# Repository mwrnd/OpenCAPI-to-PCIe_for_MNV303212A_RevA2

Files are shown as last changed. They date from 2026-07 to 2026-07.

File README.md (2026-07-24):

**Work-In-Progress**: Notes need updating. v1.1 Gerbers need to be manufactured and tested.

# PCIe to Innova-2 MNV303212A RevA2 SlimSAS8x

This is a variant of the [OpenCAPI-to-PCIe](https://github.com/mwrnd/OpenCAPI-to-PCIe) project optimized for the **Innova-2 MNV303212A Rev:A2**.

The [Open Coherant Accelerator Processor Interface (OpenCAPI)](https://opencapi.org/wp-content/uploads/2022/07/OpenCAPI-Overview.pdf) [was a standard](https://opencapi.org/2022/08/09/cxl-consortium-and-opencapi-consortium-sign-letter-of-intent-to-transfer-opencapi-specifications-to-cxl/) that had FPGA-based [Advanced Accelerated Cable (AAC)](https://files.openpower.foundation/s/xSQPe6ypoakKQdq/download/25Gbps-spec-20171108.pdf) [Add-In cards](https://opencapi.org/wp-content/uploads/2018/12/OpenCAPI-Tech-SC18-Exhibitor-Forum.pdf) such as [ADM-PCIE-9H3](https://www.alpha-data.com/product/adm-pcie-9h3/), [ADM-PCIE-9H7](https://www.alpha-data.com/alpha-data-release-adm-pcie-9h7-data-center-board-with-xilinx-virtex-ultrascale-hbm-fpga/), [ADM-PCIE-9V3](https://www.alpha-data.com/product/adm-pcie-9v3/), [ADM-PCIE-9V5](https://www.alpha-data.com/product/adm-pcie-9v5/), [BittWare XUP-VV4](https://www.bittware.com/fpga/xup-vv4/), [BittWare XUP-VVH](https://www.bittware.com/fpga/xup-vvh/), and [Nvidia Innova-2 Flex SmartNIC](https://www.nvidia.com/en-us/networking/ethernet/innova-2-flex/).

The OpenCAPI interface is based on [PCI-Express](https://en.wikipedia.org/wiki/PCI_Express) and uses a [SlimSAS 8X](https://en.wikipedia.org/wiki/Serial_Attached_SCSI) (SFF-8654) Connector. This adapter enables connecting an OpenCAPI FPGA board to a host using PCIe over a SlimSAS cable.

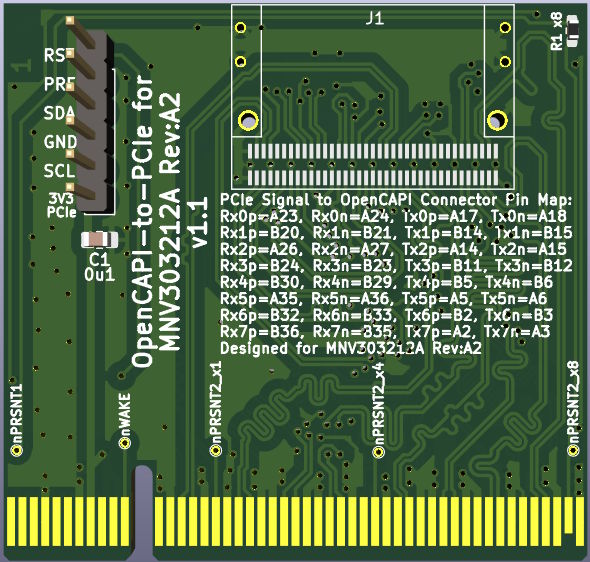
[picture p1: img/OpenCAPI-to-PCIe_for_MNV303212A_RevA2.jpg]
OpenCAPI-to-PCIe Board


## PCB Layout

4-Layer PCB. Inner 2 layers are GND planes. Differential pair are matched to a length of 61mm +/- 1mm both inter-pair and intra-pair (N-to-P).

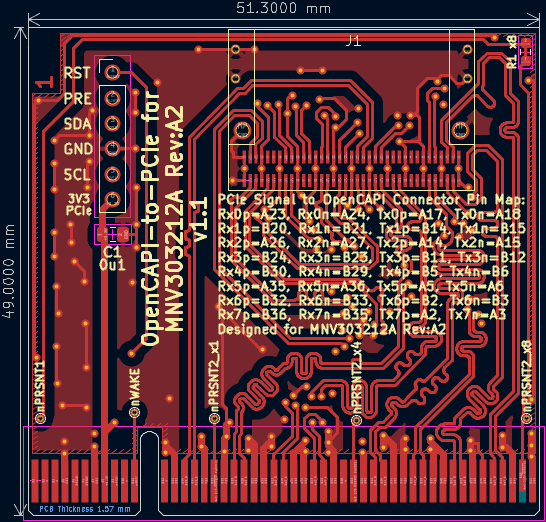
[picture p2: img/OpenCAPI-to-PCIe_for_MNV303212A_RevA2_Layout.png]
OpenCAPI to PCIe x8 PCB Layout


## Schematic

Note the reverse channel ordering and swapped `_P` and `_N` for RX3, 4, and 7. This is done to optimize for the `MNV303212A-ADLT Rev:A2` board. Technically it should not matter. PCIe features automatic `_P-to-_N` swapping and the FPGA supports arbitrary lane assignment. I did this to eliminate all possible conflating problems while tracking down reliability issues.

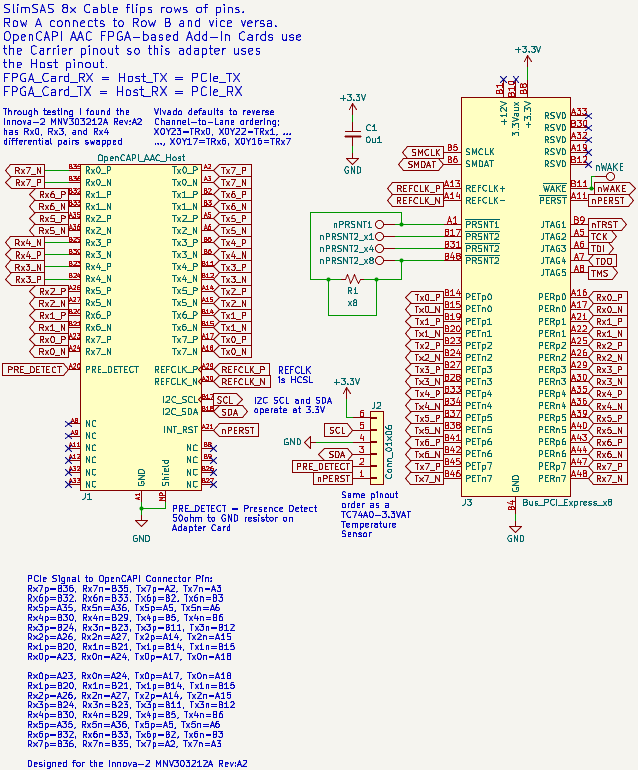
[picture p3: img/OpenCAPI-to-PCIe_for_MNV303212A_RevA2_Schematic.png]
OpenCAPI to PCIe x8 Schematic


## Design Notes

Only a single component is needed for the adapter, a [U10A474200T](https://www.digikey.com/en/products/detail/amphenol-cs-commercial-products/U10A474200T/14632855)/[U10A474240T](https://www.digikey.com/en/products/detail/amphenol-cs-commercial-products/U10A474240T/17066204) SlimSAS 8x Right-Angle SMD Connector.

A SlimSAS 8x Cable such as the [3M 8ES8-1DF21](https://www.trustedparts.com/en/search/8ES8-1DF21)([Datasheet](https://multimedia.3m.com/mws/media/1398233O/3m-slimline-twin-ax-assembly-sff-8654-x8-30awg-78-5100-2665-8.pdf)) is required to use the adapter with an OpenCAPI FPGA Board.

Resistor **R1** is shorted to connect `nPRSNT1` to `nPRSNT2_x8`. The trace can be scratched off and `nPRSNT1` can be connected to `nPRSNT2_x1` or `nPRSNT2_x4` to limit the PCIe lane width.

### PCB Stackup

I am using values from [JLCPCB](https://jlcpcb.com/capabilities/pcb-capabilities).

4-Layer Stackup

### Trace Impedance Control

OpenCAPI uses 85ohm impedance cables. I played with the values until I got the loosest differential pair coupling that is manufacturable with larger tolerances.

85ohm Differential Impedance in DigiKey Calculator

## Testing

The [innova2_xdma_opencapi](https://github.com/mwrnd/innova2_xdma_opencapi) project is designed to test this `OpenCAPI-to-PCIe for MNV303212A RevA2` Adapter using an [Innova2 Flex SmartNIC Rev:A2 board](https://github.com/mwrnd/innova2_flex_xcku15p_notes).

The Innova2 SmartNIC's XCKU15P FPGA does not have its Configuration Block in the same column as the OpenCAPI GTY transceivers so it is impossible to configure the FPGA within the [PCIe Specification's 100ms time limit](https://pcisig.com/specifications/ecr_ecn_process?speclib=100+ms).

Innova2 XCKU15P Bank Diagram

Motherboard boot must therefore be delayed to allow the FPGA to configure itself before the OpenCAPI-to-PCIe device is enumerated by the host system. This can be accomplished by toggling the POWER button, then pressing and holding the RESET button for a second before releasing it. Or, [connect a capacitor across the reset pins of an ATX motherboard's Front Panel Header](https://github.com/mwrnd/ATX_Boot_Delay):

Delay Boot Using Capacitor across Front Panel Header Reset Pins

### Cable Performance

Using a [3M 8ES8-1DF21-0.75](https://www.trustedparts.com/en/search/8ES8-1DF21-0.75) cable:

System with 3M 8ES8-1DF21-0.75 Cable

PCIe Link Status is usually excellent:

lspci Link Status

Using an [SFPCables.com SFF-8654 to SFF-8654 8i](https://www.sfpcables.com/24g-internal-slimsas-sff-8654-to-sff-8654-8i-cable-straight-to-90-degree-left-angle-8x-12-sas-4-0-85-ohm-0-5-1-meter) cable:

System with SFPCables SFF-8654 8i 85Ohm Cable

PCIe Link Status is downgraded:

lspci Link Status

### Additional OpenCAPI Signals

Additional useful signals from the OpenCAPI connector are routed to a 6x1 0.1" Header ([DigiKey](https://www.digikey.com/en/products/detail/sullins-connector-solutions/PPTC061LFBN-RC/810145)). The pinout matches a [TC74 I2C Temperature Sensor](https://www.microchip.com/en-us/product/tc74) ([DigiKey](https://www.digikey.com/en/products/detail/microchip-technology/TC74A0-3-3VAT/442720)) for testing I2C. I2C pull-ups are on the AAC Add-in card (Innova-2). Note 3.3V is from the PCIe connector. **PRE** is a Presence Detect pin which is connected to GND via a 50-Ohm resistor on the OpenCAPI AAC Add-In card (Innova-2). **RST** is connected to PCIe/OpenCAPI RESET.

TC74A0-3.3VAT in OpenCAPI-to-PCIe Adapter

The [innova2_xdma_opencapi](https://github.com/mwrnd/innova2_xdma_opencapi) project features the ability to [test](https://github.com/mwrnd/innova2_xdma_opencapi/blob/main/README.md#opencapi-i2c-over-xdma) a TC74Ax-3.3VAT in an OpenCAPI-to-PCIe Adapter.

TC74A0-3.3VAT Testing in a System

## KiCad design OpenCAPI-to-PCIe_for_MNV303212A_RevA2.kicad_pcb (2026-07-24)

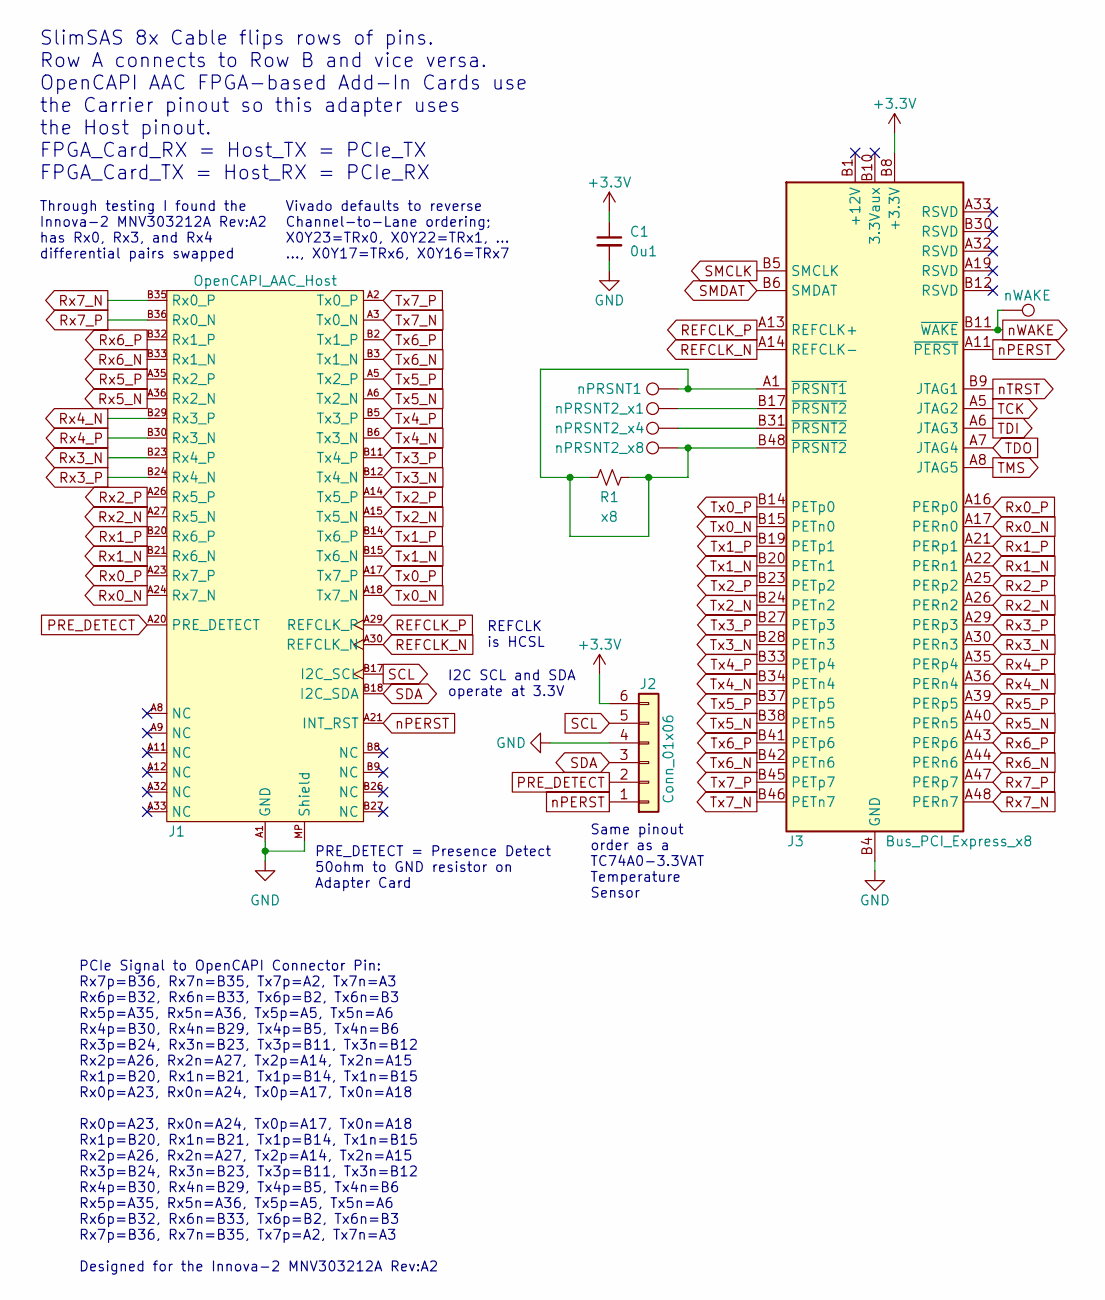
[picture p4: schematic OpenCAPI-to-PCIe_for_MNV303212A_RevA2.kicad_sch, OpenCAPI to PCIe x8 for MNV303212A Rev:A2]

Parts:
C1: 0u1; C_0805_2012Metric_Pad1.18x1.45mm_HandSolder
J1: OpenCAPI_AAC_Host; SlimSAS_8x_RA_U10-A474
J2: Conn_01x06; PinHeader_1x06_P2.54mm_Vertical
J3: Bus_PCI_Express_x8; BUS_PCIexpress_x8
R1: x8; R_0603_1608Metric_Pad0.98x0.95mm_HandSolder
TP1: nPRSNT1; TestPoint_THTPad_D1.0mm_Drill0.5mm
TP2: nPRSNT2_x1; TestPoint_THTPad_D1.0mm_Drill0.5mm
TP3: nPRSNT2_x4; TestPoint_THTPad_D1.0mm_Drill0.5mm
TP4: nWAKE; TestPoint_THTPad_D1.0mm_Drill0.5mm
TP5: nPRSNT2_x8; TestPoint_THTPad_D1.0mm_Drill0.5mm

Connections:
+3.3V: C1.1, J2.6, J3.A9 (+3.3V), J3.A10 (+3.3V), J3.B8 (+3.3V)
GND: C1.2, J1.A1 (GND), J1.A4 (GND), J1.A7 (GND), J1.A10 (GND), J1.A13 (GND), J1.A16 (GND), J1.A19 (GND), J1.A22 (GND), J1.A25 (GND), J1.A28 (GND), J1.A31 (GND), J1.A34 (GND), J1.A37 (GND), J1.B1 (GND), J1.B4 (GND), J1.B7 (GND), J1.B10 (GND), J1.B13 (GND), J1.B16 (GND), J1.B19 (GND), J1.B22 (GND), J1.B25 (GND), J1.B28 (GND), J1.B31 (GND), J1.B34 (GND), J1.B37 (GND), J1.MP (Shield), J2.4, J3.A4 (GND), J3.A12 (GND), J3.A15 (GND), J3.A18 (GND), J3.A20 (GND), J3.A23 (GND), J3.A24 (GND), J3.A27 (GND), J3.A28 (GND), J3.A31 (GND), J3.A34 (GND), J3.A37 (GND), J3.A38 (GND), J3.A41 (GND), J3.A42 (GND), J3.A45 (GND), J3.A46 (GND), J3.A49 (GND), J3.B4 (GND), J3.B7 (GND), J3.B13 (GND), J3.B16 (GND), J3.B18 (GND), J3.B21 (GND), J3.B22 (GND), J3.B25 (GND), J3.B26 (GND), J3.B29 (GND), J3.B32 (GND), J3.B35 (GND), J3.B36 (GND), J3.B39 (GND), J3.B40 (GND), J3.B43 (GND), J3.B44 (GND), J3.B47 (GND), J3.B49 (GND)
unnamed: J3.A1 (~PRSNT1), J3.B48 (~PRSNT2), R1.1, R1.2, TP1.1, TP5.1
unnamed: J3.B17 (~PRSNT2), TP2.1
unnamed: J3.B31 (~PRSNT2), TP3.1
PRE_DETECT: J1.A20 (PRE_DETECT), J2.2
REFCLK_N: J1.A30 (REFCLK_N), J3.A14 (REFCLK-)
REFCLK_P: J1.A29 (REFCLK_P), J3.A13 (REFCLK+)
Rx0_N: J1.A24 (Rx7_N), J3.A17 (PERn0)
Rx0_P: J1.A23 (Rx7_P), J3.A16 (PERp0)
Rx1_N: J1.B21 (Rx6_N), J3.A22 (PERn1)
Rx1_P: J1.B20 (Rx6_P), J3.A21 (PERp1)
Rx2_N: J1.A27 (Rx5_N), J3.A26 (PERn2)
Rx2_P: J1.A26 (Rx5_P), J3.A25 (PERp2)
Rx3_N: J1.B23 (Rx4_P), J3.A30 (PERn3)
Rx3_P: J1.B24 (Rx4_N), J3.A29 (PERp3)
Rx4_N: J1.B29 (Rx3_P), J3.A36 (PERn4)
Rx4_P: J1.B30 (Rx3_N), J3.A35 (PERp4)
Rx5_N: J1.A36 (Rx2_N), J3.A40 (PERn5)
Rx5_P: J1.A35 (Rx2_P), J3.A39 (PERp5)
Rx6_N: J1.B33 (Rx1_N), J3.A44 (PERn6)
Rx6_P: J1.B32 (Rx1_P), J3.A43 (PERp6)
Rx7_N: J1.B35 (Rx0_P), J3.A48 (PERn7)
Rx7_P: J1.B36 (Rx0_N), J3.A47 (PERp7)
SCL: J1.B17 (I2C_SCL), J2.5
SDA: J1.B18 (I2C_SDA), J2.3
SMCLK: J3.B5 (SMCLK)
SMDAT: J3.B6 (SMDAT)
TCK: J3.A5 (JTAG2)
TDI: J3.A6 (JTAG3)
TDO: J3.A7 (JTAG4)
TMS: J3.A8 (JTAG5)
Tx0_N: J1.A18 (Tx7_N), J3.B15 (PETn0)
Tx0_P: J1.A17 (Tx7_P), J3.B14 (PETp0)
Tx1_N: J1.B15 (Tx6_N), J3.B20 (PETn1)
Tx1_P: J1.B14 (Tx6_P), J3.B19 (PETp1)
Tx2_N: J1.A15 (Tx5_N), J3.B24 (PETn2)
Tx2_P: J1.A14 (Tx5_P), J3.B23 (PETp2)
Tx3_N: J1.B12 (Tx4_N), J3.B28 (PETn3)
Tx3_P: J1.B11 (Tx4_P), J3.B27 (PETp3)
Tx4_N: J1.B6 (Tx3_N), J3.B34 (PETn4)
Tx4_P: J1.B5 (Tx3_P), J3.B33 (PETp4)
Tx5_N: J1.A6 (Tx2_N), J3.B38 (PETn5)
Tx5_P: J1.A5 (Tx2_P), J3.B37 (PETp5)
Tx6_N: J1.B3 (Tx1_N), J3.B42 (PETn6)
Tx6_P: J1.B2 (Tx1_P), J3.B41 (PETp6)
Tx7_N: J1.A3 (Tx0_N), J3.B46 (PETn7)
Tx7_P: J1.A2 (Tx0_P), J3.B45 (PETp7)
nPERST: J1.A21 (INT_RST), J2.1, J3.A11 (~PERST)
nTRST: J3.B9 (JTAG1)
nWAKE: J3.B11 (~WAKE), TP4.1

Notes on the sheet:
I2C SCL and SDA operate at 3.3V
Same pinout order as a TC74A0-3.3VAT Temperature Sensor
Vivado defaults to reverse Channel-to-Lane ordering; X0Y23=TRx0, X0Y22=TRx1, ... ..., X0Y17=TRx6, X0Y16=TRx7
REFCLK is HCSL
PCIe Signal to OpenCAPI Connector Pin: Rx7p=B36, Rx7n=B35, Tx7p=A2, Tx7n=A3 Rx6p=B32, Rx6n=B33, Tx6p=B2, Tx6n=B3 Rx5p=A35, Rx5n=A36, Tx5p=A5, Tx5n=A6 Rx4p=B30, Rx4n=B29, Tx4p=B5, Tx4n=B6 Rx3p=B24, Rx3n=B23, Tx3p=B11, Tx3n=B12 Rx2p=A26, Rx2n=A27, Tx2p=A14, Tx2n=A15 Rx1p=B20, Rx1n=B21, Tx1p=B14, Tx1n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
SlimSAS 8x Cable flips rows of pins. Row A connects to Row B and vice versa. OpenCAPI AAC FPGA-based Add-In Cards use the Carrier pinout so this adapter uses the Host pinout. FPGA_Card_RX = Host_TX = PCIe_TX FPGA_Card_TX = Host_RX = PCIe_RX
PRE_DETECT = Presence Detect 50ohm to GND resistor on Adapter Card
Through testing I found the Innova-2 MNV303212A Rev:A2 has Rx0, Rx3, and Rx4 differential pairs swapped

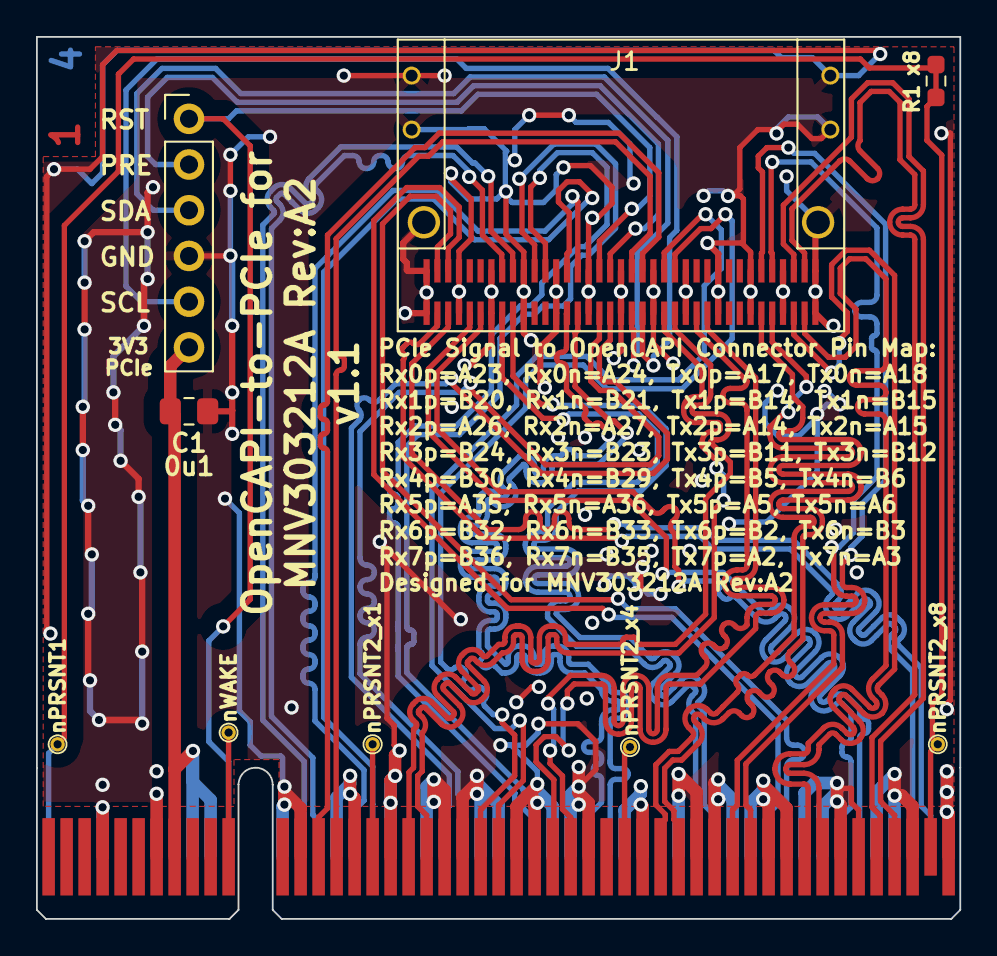
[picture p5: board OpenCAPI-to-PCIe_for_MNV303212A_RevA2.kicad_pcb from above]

Board: 4 copper layers, 51.3 x 49.0 mm, 10 parts (0 on the bottom side), 44 nets.

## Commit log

2026-07-22 Updated with new Name
    [OpenCAPI-to-PCIe.kicad_pcb, OpenCAPI-to-PCIe.kicad_sch, OpenCAPI-to-PCIe_for_MNV303212A_RevA2.kicad_pcb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]
2026-07-24 Fixed GND Plane
    [OpenCAPI-to-PCIe_for_MNV303212A_RevA2.kicad_pcb]
